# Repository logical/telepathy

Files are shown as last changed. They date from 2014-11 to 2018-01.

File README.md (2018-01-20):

THIS PROJECT IS DISCONTINUED FOR NOW.

The research is proving more difficult than I have hoped and there are alternatives available.

This is telepathy the mostly HARDWARE project not telepathy the software project
Sorry for my lack of creativity in choosing a name.

This poject contains an EXPERIMENTAL wireless eeg circuit.

GOAL
------
This project is under development so it is not working. I welcome suggestions.

The goal is to do brain computer interface experments.I want to make a wireless headband that runs
on a battery. 

It contains.

STATUS
------
I made one pcb but it didn't work. I'm still interested in the project so I am currently doing 
a complete redesign of the hardware. I will be etching the boards myself they will be single sided SMT 
and divided in sections.Here are some of the changes I'm planning. 

1. Split the device into sections for power, amplifier and input/output.
2. Replace the wireless module and pic with a wireless capable microcontroller. (telepathy with esp8266?)
3. The whole design will be based on active electrodes.

ELECTRODES: 

I have 2 designs for active electrodes. Active dry electrodes and active noncontact electrodes.
The dry electrodes are based on the openeeg design. The noncontact electrodes are based on a design I found here:

http://www.isn.ucsd.edu/pubs/bsn10.pdf

I'm assuming it is creative commons.

AMPLIFIER BOARD:

The amplifier board is under testing I plan to use one filter for aliasing and filter the rest in software. None
 of the resistor and capacitor values are decided yet.  
I have the source voltage at 3.3v from a cell phone battery. So far I can pick up a heartbeat .

EEGDATA:

A GUI software program for linux that retreives the data from the /dev/rfcomm0 bluetooth serial terminal
and analyzes and displays the data. I started the project in C but it was more convenient to write the data analysis portion in C++. 

On my system I use these commands to setup the bluetooth serial port.

 	#find the address
 	$hcitool scan
	#bind the address
	$sudo rfcomm bind rfcomm0 device_address
	
For BLE

	#find the adapter address
	$hcitool dev
	#find the device address
	$sudo hcitool -i hci0 lescan

Then you need to run any programs that access serial terminal as root unless you have sufficient permission.

FIRMWARE:

The firmware is for a PIC microcontroller 16f1788 and a bluetooth serial module hc-05.

I have wrote a bootloader so I can more easily install firmware.The bootloader sets the hc-05 up at 38400 and waits for a program.
When the program successfully loads it sets a byte in ee memory.when the FLASH command is sent to the program it erases the byte
so the bootloader will again wait for a progam. You can use a standard serial terminal to send the program but you have to set a long delay (~30ms) between characters so the program has time to write. Custom coding the serial interface for the bootloader would be faster but this works for now.

Hopefully I have no glitches in the bootloader or a firmware update could brick the device! 
If so the glitch would have to be fixed and the bootloader reprogrammed.

The microcontroller first sets up the hc-05 at 230400, then wait for a request.When it receives  a request it begins sampling the analog to digital converter and sending the samples to the hc-05.

I have included the makefiles so they should build with the make command but they may require modification . MPLABX should be able to load them as a makefile project but I have not tried.

SCHEMATIC:

I'm developing the amplifier board first. amplifier-board.png is the current design.

DISCLAIMER:

This project is an EXPERIMENT. I make no claims that it actually does anything.It may be harmful to 
individuals or property.
THIS DEVICE AND SOFTWARE MAY BE DANGEROUS. DO NOT BUILD IT.

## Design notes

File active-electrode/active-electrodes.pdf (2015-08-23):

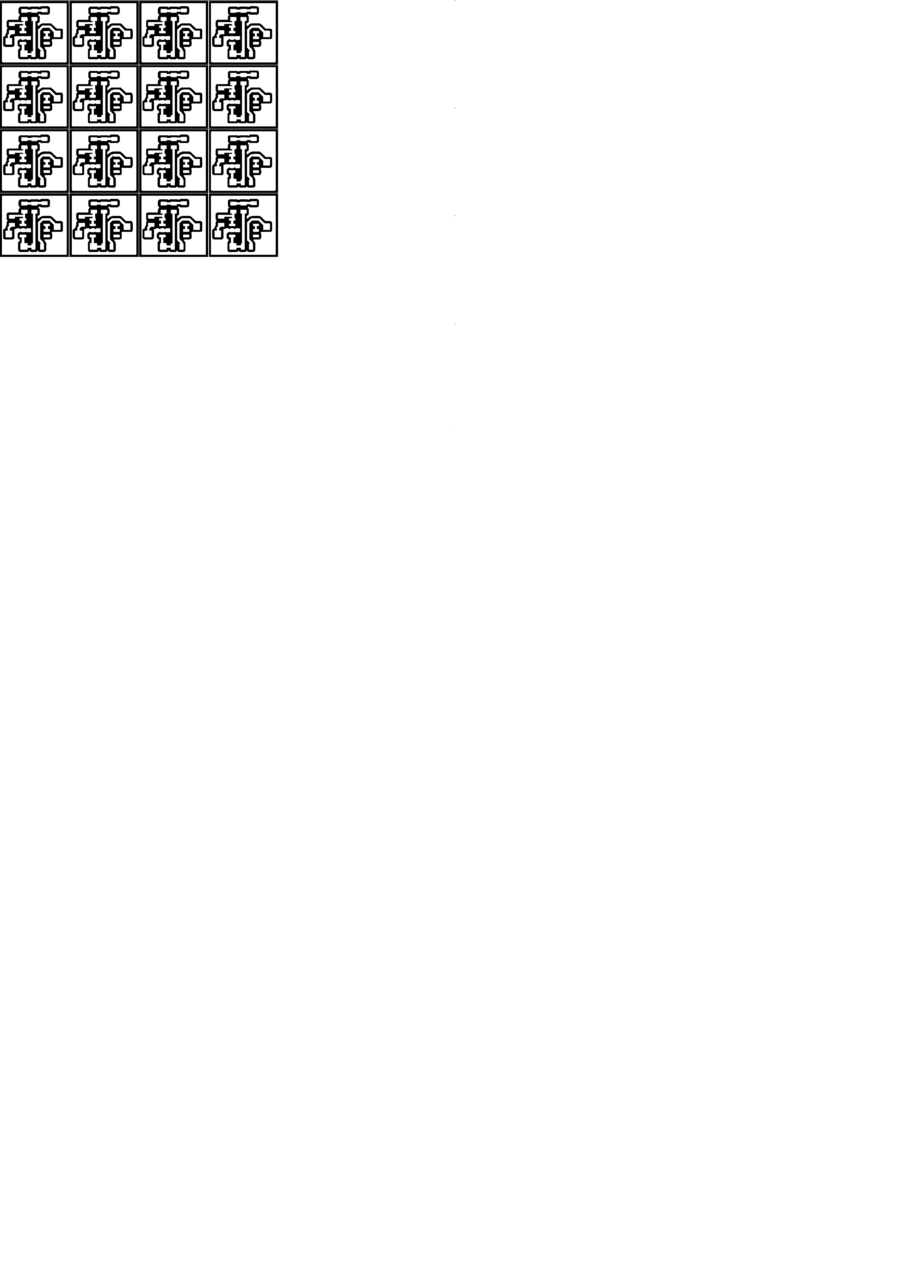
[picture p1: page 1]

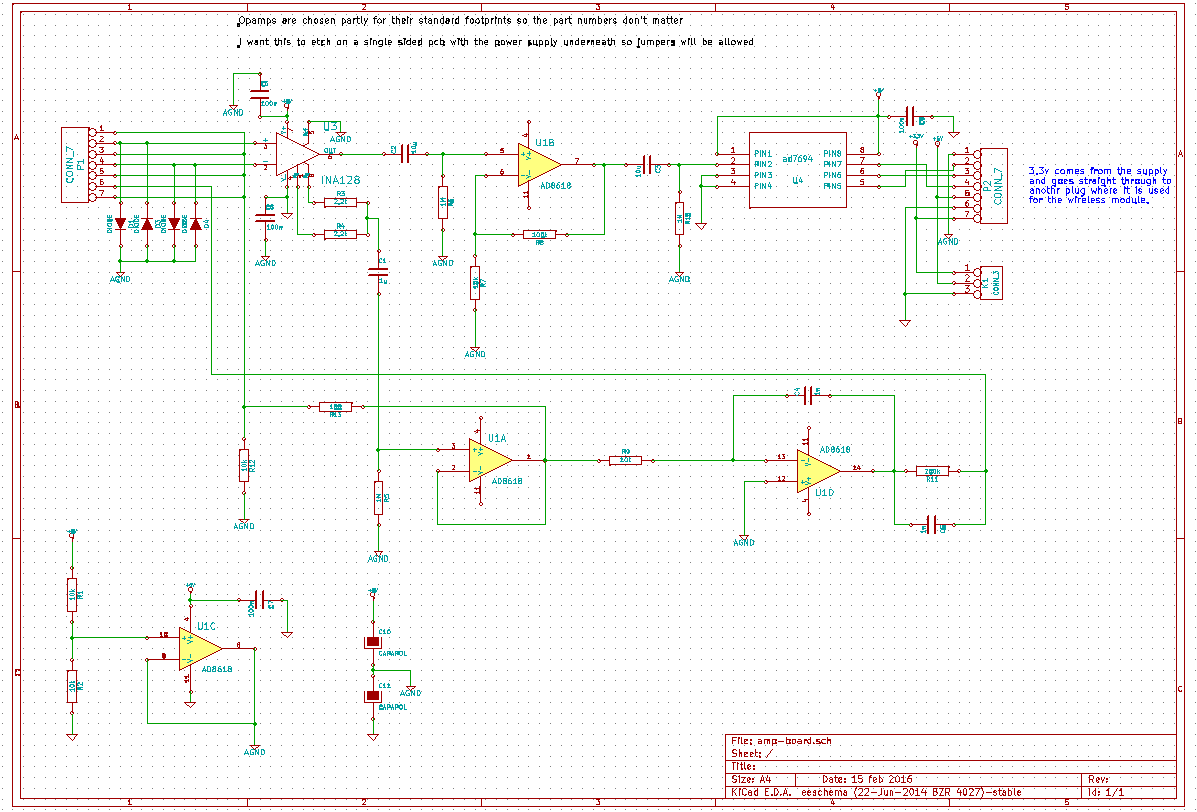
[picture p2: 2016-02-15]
amplifier-board.png

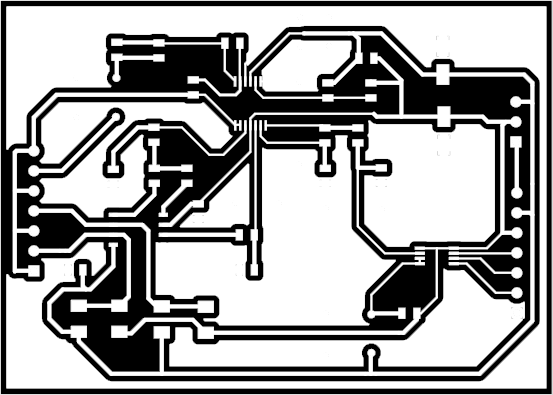
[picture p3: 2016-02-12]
amplifier-board/amp-board-F_Cu.png

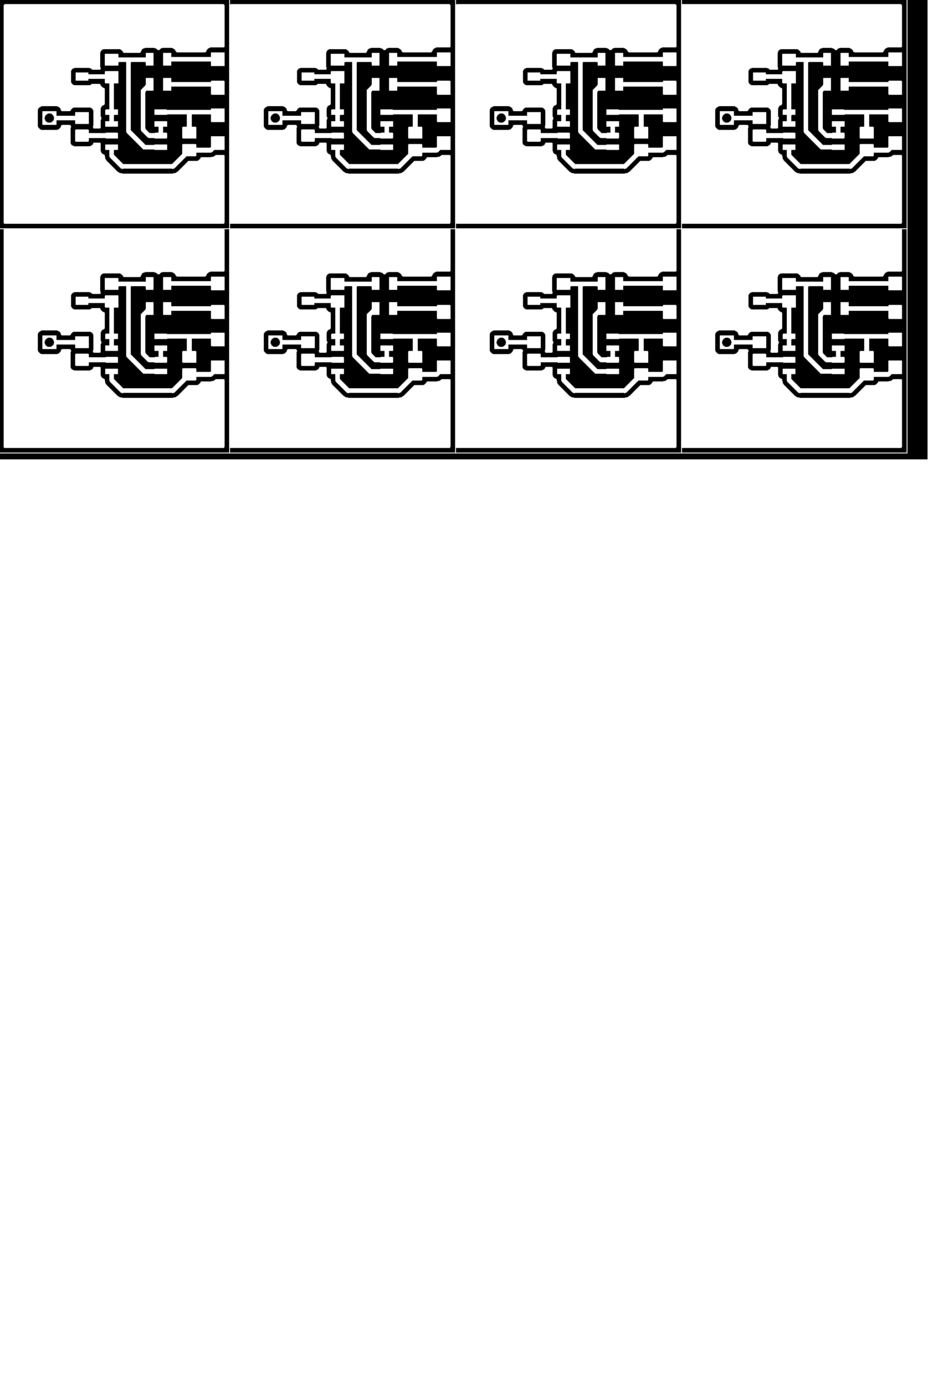
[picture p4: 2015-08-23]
noncontact-electrodes/noncontact-electrodes-F_Cu.png

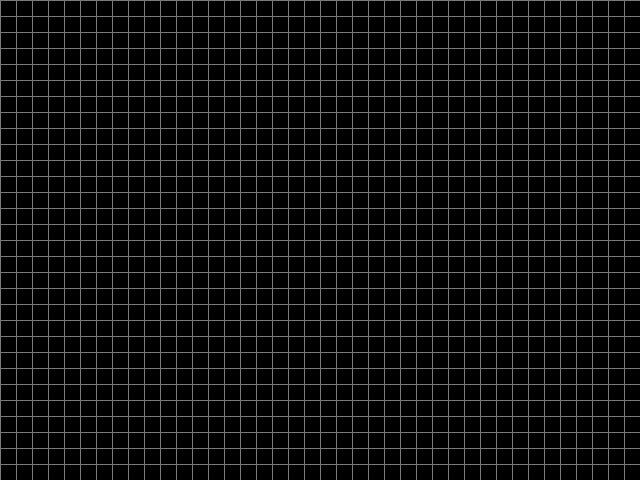
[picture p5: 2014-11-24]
eegdata/grid.png

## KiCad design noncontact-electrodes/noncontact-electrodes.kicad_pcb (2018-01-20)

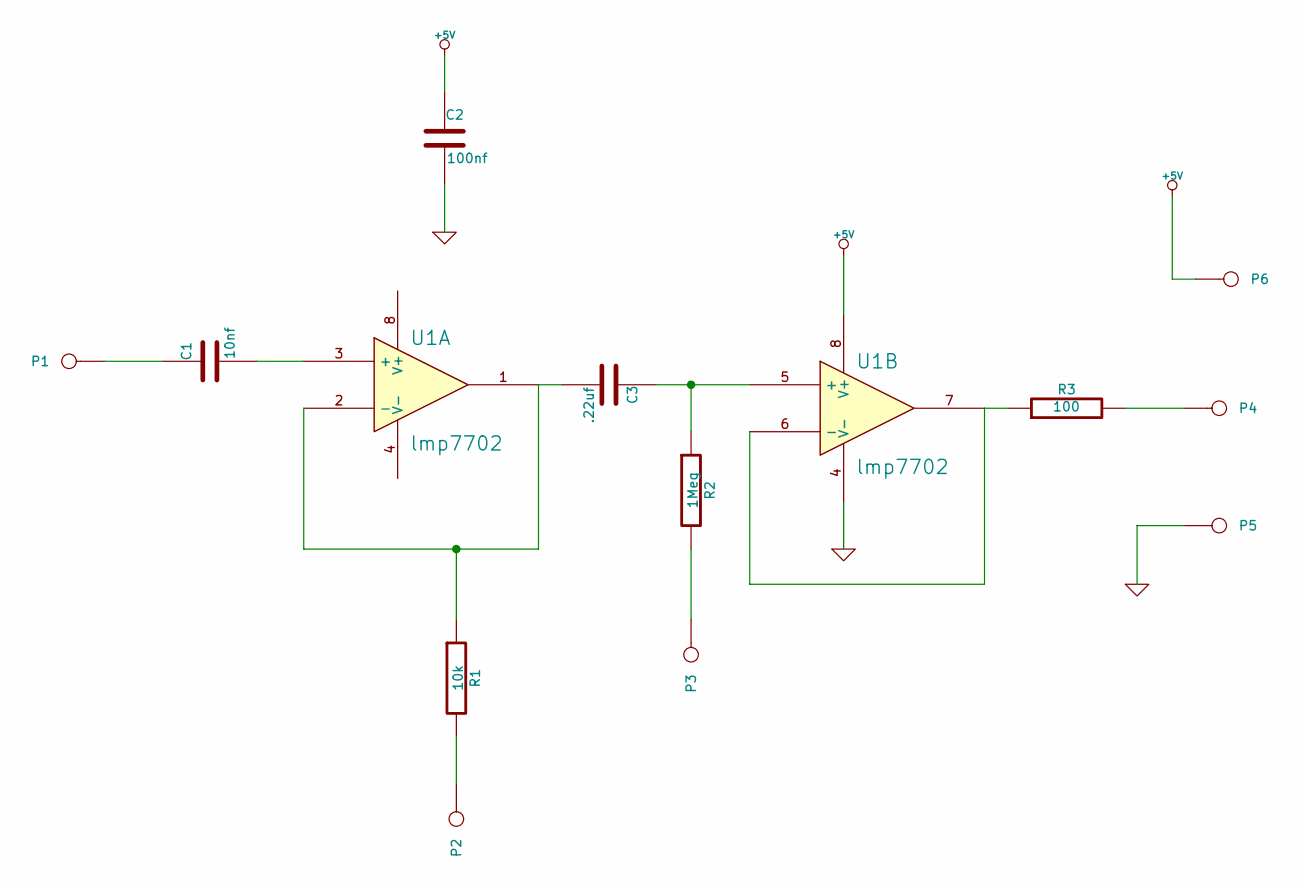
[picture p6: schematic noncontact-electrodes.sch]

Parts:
C1: 10nf
C2: 100nf
C3: .22uf
P1, P2, P3, P4, P5, P6: CONN_1
R1: 10k
R2: 1Meg
R3: 100
U1: lmp7702

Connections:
+5V: C2.1, P6.1, U1.8 (V+)
GND: C2.2, P5.1, U1.4 (V-)
unnamed: P2.1, R1.2
unnamed: C1.1, P1.1
unnamed: P4.1, R3.2
unnamed: P3.1, R2.2
unnamed: C1.2, U1.3 (+)
unnamed: C3.2, R1.1, U1.1, U1.2 (-)
unnamed: R3.1, U1.6 (-), U1.7
unnamed: C3.1, R2.1, U1.5 (+)

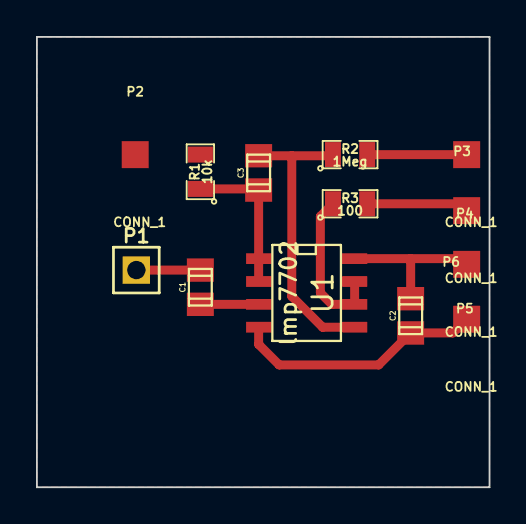
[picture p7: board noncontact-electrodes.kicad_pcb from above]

Board: 2 copper layers, 25.1 x 25.0 mm, 13 parts (0 on the bottom side), 10 nets.

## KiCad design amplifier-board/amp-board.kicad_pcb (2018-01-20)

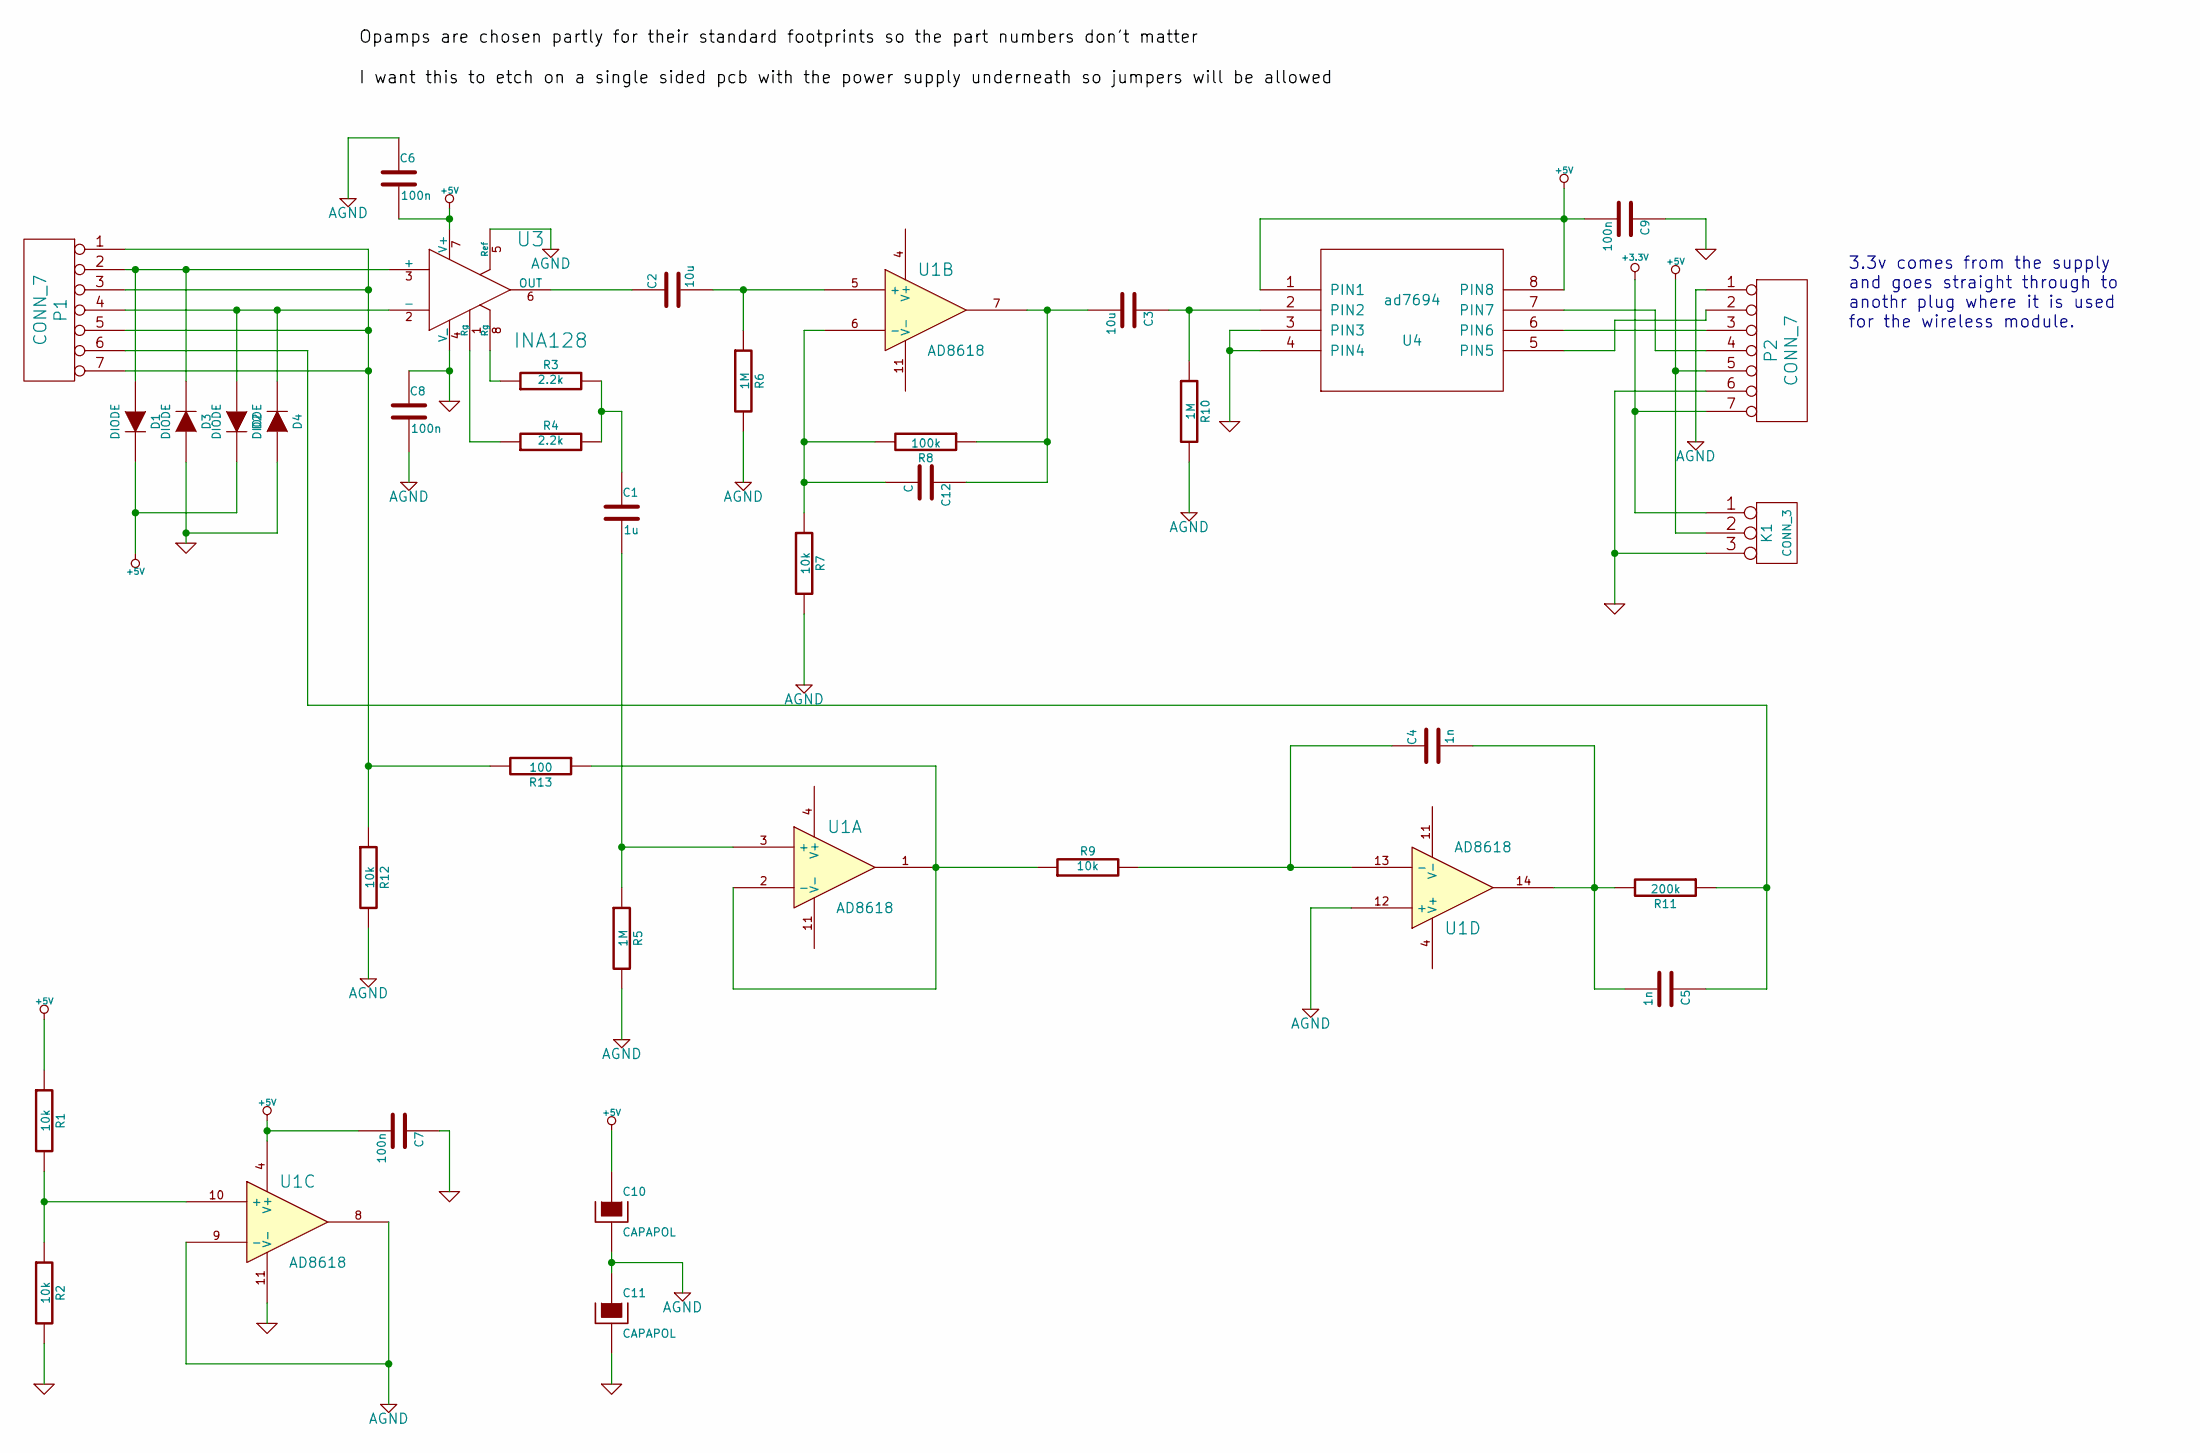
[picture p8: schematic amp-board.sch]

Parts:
C1: 1u
C2, C3: 10u
C4, C5: 1n
C6, C7, C8, C9: 100n
C10, C11: CAPAPOL
C12: C
D1, D2, D3, D4: DIODE
K1: CONN_3
P1, P2: CONN_7
R1, R2, R7, R9, R12: 10k
R3, R4: 2.2k
R5, R6, R10: 1M
R8: 100k
R11: 200k
R13: 100
U1: AD8618
U3: INA128
U4: ad7694; MODULE

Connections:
+3.3V: K1.1, P2.7
+5V: C6.2, C7.2, C9.2, C10.1, D1.2 (K), D2.2 (K), K1.2 (PM), P2.5, R1.1, U1.4 (V+), U3.7 (V+), U4.1 (PIN1), U4.8 (PIN8)
AGND: C6.1, C8.2, C10.2, C11.1, P2.1, R5.2, R6.2, R7.2, R10.2, R12.2, U1.8, U1.9 (-), U1.12 (+), U3.5 (Ref)
GND: C7.1, C8.1, C9.1, C11.2, D3.1 (A), D4.1 (A), K1.3, P2.6, R2.2, U1.11 (V-), U3.4 (V_), U4.3 (PIN3), U4.4 (PIN4)
unnamed: R9.1, R13.1, U1.1, U1.2 (-)
unnamed: C4.1, R9.2, U1.13 (-)
unnamed: C4.2, C5.2, R11.2, U1.14
unnamed: C5.1, P1.6, R11.1
unnamed: C1.2, R5.1, U1.3 (+)
unnamed: C1.1, R3.2, R4.2
unnamed: C3.1, R10.1, U4.2 (PIN2)
unnamed: C3.2, C12.1, R8.1, U1.7
unnamed: R1.2, R2.1, U1.10 (+)
unnamed: C2.2, R6.1, U1.5 (+)
unnamed: C2.1, U3.6 (OUT)
unnamed: R4.1, U3.1 (Rg)
unnamed: R3.1, U3.8 (Rg)
unnamed: D2.1 (A), D4.2 (K), P1.4, U3.2 (-)
unnamed: C12.2, R7.1, R8.2, U1.6 (-)
unnamed: D1.1 (A), D3.2 (K), P1.2, U3.3 (+)
unnamed: P2.3, U4.6 (PIN6)
unnamed: P2.2, U4.5 (PIN5)
unnamed: P2.4, U4.7 (PIN7)
unnamed: P1.1, P1.3, P1.5, P1.7, R12.1, R13.2

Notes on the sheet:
3.3v comes from the supply and goes straight through to anothr plug where it is used for the wireless module.

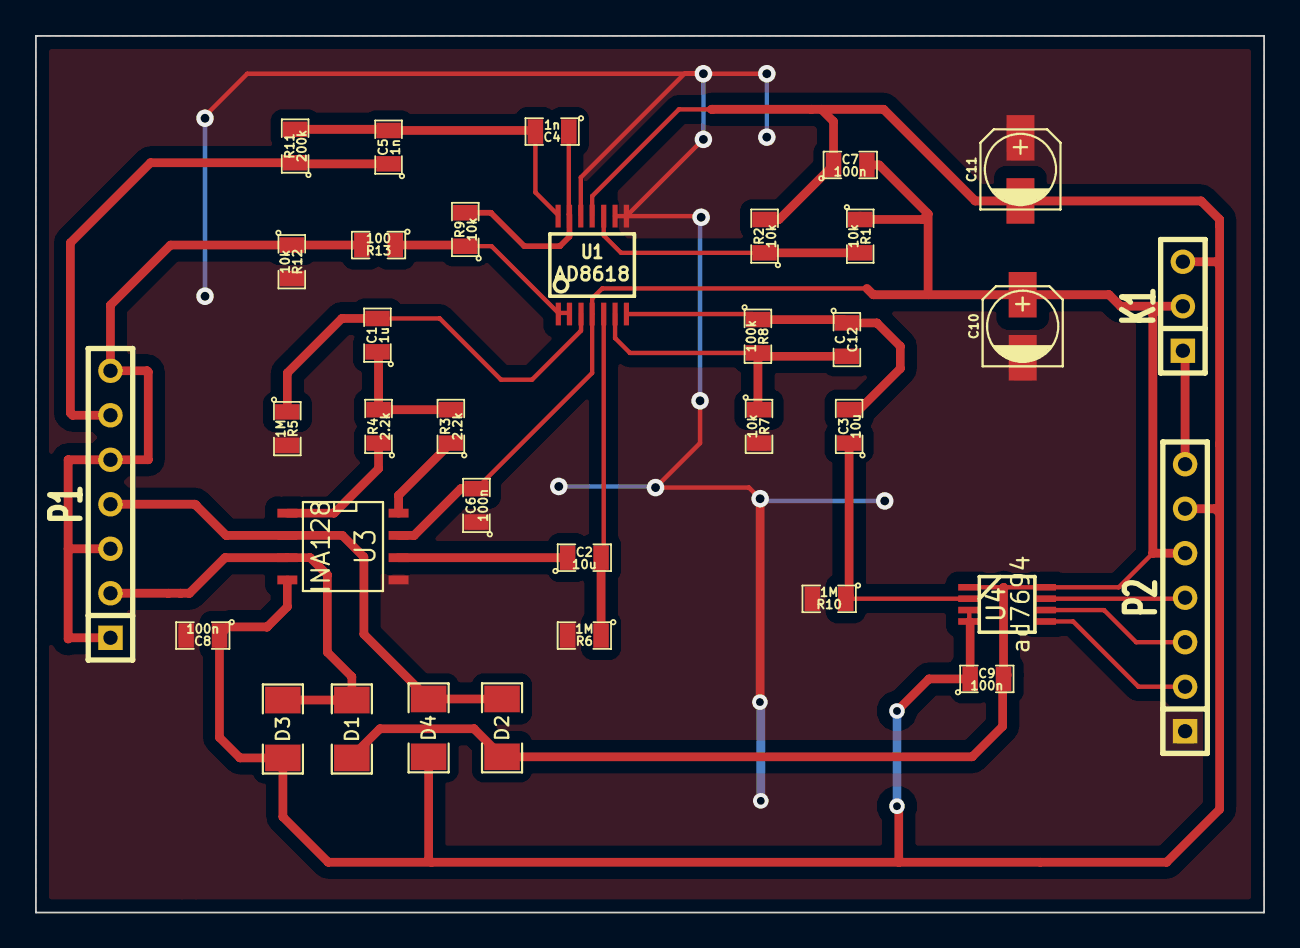
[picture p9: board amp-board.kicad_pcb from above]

Board: 2 copper layers, 70.1 x 50.0 mm, 35 parts (0 on the bottom side), 24 nets.

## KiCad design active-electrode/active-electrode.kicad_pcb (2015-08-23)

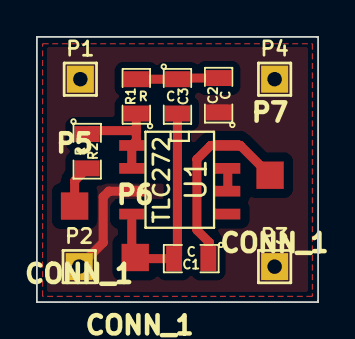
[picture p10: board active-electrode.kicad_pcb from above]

Board: 2 copper layers, 15.6 x 14.7 mm, 13 parts (0 on the bottom side), 7 nets.

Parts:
C1, C2, C3: C; SM0805
P1, P2, P3, P4: CONN_1; SIL-1
P5, P6, P7: CONN_1; 1PIN_SMD
R1, R2: R; SM0805
U1: TLC272; SO8E

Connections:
+5V: C1.1, P7.1, U1.8
GND: C1.2, C3.2, P6.1, U1.4
unnamed: U1.6, U1.7
unnamed: C2.2, C3.1, R1.2
unnamed: R1.1, R2.1, U1.1, U1.2
unnamed: P5.1, R2.2
unnamed: C2.1, P1.1, P2.1, P3.1, P4.1, U1.3

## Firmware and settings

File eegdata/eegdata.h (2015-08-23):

#ifndef EEGDATA_H
#define EEGDATA_H

#include <gtk/gtk.h>
#include <gdk/gdk.h>

#include <glib/gprintf.h>
#include "cvanalyze.h"
#include "eegdatarxtx.h"
 
#ifdef __cplusplus
extern "C" {
#endif

#define FRAMEDELAY 50
#define DEFAULT_FILE    "./telepathy-eeg.dat"
#define RXTXPROCESS     "./eegdatarxtx"
#define FIFONAME	"./eegdatafifo"
#define SAVE_FILE	"./eegdatasettings"
       

  
#define UI_FILE "ui3.ui"
#define SCOPEWIDTH 640
#define SCOPEHEIGHT 480
#define WRITESIZE 32 //number of samples to write at once
#define YSCALE ((float)SCOPEHEIGHT/(float)MAXSAMPLE)
#define XSCALE (SCOPEWIDTH/(SAMPLESIZE/2))
#define RESISTOR 255 //this sets the resistor value that sets the final amplifier gain  

#define DEFAULT_COM	"/dev/rfcomm1"
#define DEFAULT_BAUD	B230400 

  
pthread_t rxthread;

char mode;

GtkWidget *video,*signalview,*chan1check,*chan2check,*chan3check,*chan4check,*timecheck,*freqcheck,*savedialog,*startbutton,*devicechoice,*rangespin;
GtkWidget *savename[TRIGGERS],*saveaction[TRIGGERS],*savebutton[TRIGGERS],*deletebutton[TRIGGERS],*activebutton[TRIGGERS];
GdkPixbuf *grid;




double volts,trig,chron;
unsigned short selectedrow;
unsigned char RequestedRange;

cairo_surface_t *background,*scope;

union{
    struct{
    unsigned DONE   :1;  
    unsigned DATA   :1;  
    };

}controlbits;



GtkWidget* create_window (void);
void drawingarea1_draw_event_cb(GtkWidget *widget, gpointer gdata);
void drawingarea2_draw_event_cb(GtkWidget *widget, gpointer gdata);
void open_save_patterns( GtkWidget *widget , gpointer data);
void save_pattern( GtkWidget *widget , gpointer data);
void start( GtkWidget *widget , gpointer data);
void destroy (GtkWidget *widget, gpointer data);

void microsleep(unsigned int us);
void trace(cairo_t* sc,unsigned short *data,unsigned int size);
int SetupConnection(int port, int baudRate);
int receive(int port,unsigned char *rxbuffer,unsigned int length);
void fakepackets(unsigned int length);
void read_settings_file(void);
void save_settings_file(void);
void getdata(void);
int setrange(int range);
void writepackets(void);


#ifdef __cplusplus
} 
#endif


#endif

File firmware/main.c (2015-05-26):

/*
 * File:   main.c
 * Author: logical
 *
 * Created on December 7, 2014, 10:37 AM
 *   The byte format is:
 *
 * MSB channel 1/LSB channel 1/MSB channel 2/LSB channel 2/MSB channel 3/LSB channel 3/MSB channel 4/LSB channel 4/
 * the control character are:
 *
 * s : sample 256 samples and send 512 bytes per channel
 *
 * t :to transmitter by sending "hello\n"
 *
 * r XXX :set gain of amplifier by increasing and decreasing rf of non inverting opamp. 
 *
 *
 */

#include <string.h>
#include <stdlib.h>
#include <pic16f1788.h>
#include <xc.h>

#define NO_BIT_DEFINES
#define BOOTLOAD
#ifndef BOOTLOAD
#pragma config FOSC = INTOSC    // Oscillator Selection (INTOSC oscillator: I/O function on CLKIN pin)
#pragma config WDTE = OFF       // Watchdog Timer Enable (WDT disabled)
#pragma config PWRTE = OFF      // Power-up Timer Enable (PWRT disabled)
#pragma config MCLRE = ON       // MCLR Pin Function Select (MCLR/VPP pin function is MCLR)
#pragma config CP = OFF         // Flash Program Memory Code Protection (Program memory code protection is disabled)
#pragma config CPD = OFF        // Data Memory Code Protection (Data memory code protection is disabled)
#pragma config BOREN = OFF      // Brown-out Reset Enable (Brown-out Reset disabled)
#pragma config CLKOUTEN = OFF   // Clock Out Enable (CLKOUT function is disabled. I/O or oscillator function on the CLKOUT pin)
#pragma config IESO = ON      // Internal/External Switchover (Internal/External Switchover mode is disabled)
#pragma config FCMEN = OFF      // Fail-Safe Clock Monitor Enable (Fail-Safe Clock Monitor is disabled)

#pragma config WRT = OFF        // Flash Memory Self-Write Protection (Write protection off)
#pragma config VCAPEN = OFF     // Voltage Regulator Capacitor Enable bit (Vcap functionality is disabled on RA6.)
#pragma config PLLEN = OFF      // PLL Enable (4x PLL disabled)
#pragma config STVREN = OFF     // Stack Overflow/Underflow Reset Enable (Stack Overflow or Underflow will not cause a Reset)
#pragma config BORV = HI        // Brown-out Reset Voltage Selection (Brown-out Reset Voltage (Vbor), low trip point selected.)
#pragma config LPBOR = OFF      // Low Power Brown-Out Reset Enable Bit (Low power brown-out is disabled)
#pragma config LVP = OFF        // Low-Voltage Programming Enable (High-voltage on MCLR/VPP must be used for programming)

#endif


/*pin defines*/

#define ERROR_PIN PORTAbits.RA6

/*
 * MC4130 digital potentiometer 
 * 
 */

#define POT_CS_PIN PORTCbits.RC1
#define ADC_CONV_PIN PORTCbits.RC2
#define SCK_PIN PORTCbits.RC3
#define SDI_PIN PORTCbits.RC4
#define SDO_PIN PORTCbits.RC5

/*
 * AD409 analog multiplexer
 */

#define MPX_A_PIN PORTBbits.RB0
#define MPX_B_PIN PORTBbits.RB1

/*
 * These outputs ground unused multiplexer inputs to prevent crosstalk
 */

#define GND_IN_0 PORTBbits.RB2
#define GND_IN_1 PORTBbits.RB3
#define GND_IN_2 PORTBbits.RB4
#define GND_IN_3 PORTBbits.RB5


/*
 * UART for the HC-05
 */
#define CMD_PIN PORTCbits.RC0
#define TX_PIN	PORTCbits.RC6
#define RX_PIN	PORTCbits.RC7



#define BAUD_230400 2
#define BAUD_38400 1

#define PACKETSIZE 8
#define MAXSAMPLE 65535 

struct{
    unsigned char size;
    unsigned char elems[64];
    unsigned flag :1;
}rxbuffer,txbuffer;


#define XON 0x11
#define XOFF 0x13
#define START 0x12
#define STOP 0x14
#define TESTMODE 0x07

union{
    struct{
    unsigned FLOW    :1;
    unsigned DATA    :1; 
    unsigned TEST    :1;
    unsigned RX      :1;
    unsigned TX      :1;
    unsigned CH1     :1;
    unsigned CH2     :1;
    };

}controlbits;


unsigned char delay_count1;


void delay_100us(unsigned int count){
/*
 *  ; Delay = 0.0001 seconds
 *  ; Clock frequency = 8 MHz
 *  ;798 cycles
 * 
 */
    while(count--){
        asm("movlw	0x41");
        asm("movwf	_delay_count1");
        asm("Delay_1    ");
        asm("decfsz	_delay_count1, f");
        asm("goto	Delay_1");
    }

}

void flasherror(unsigned char flashes){
    for(unsigned char f=0;f<flashes;f++){
            ERROR_PIN=1;
            delay_100us(2000);
            ERROR_PIN=0;
            delay_100us(2000);
        }
            delay_100us(5000);
}
unsigned int bytecount=0;

void interrupt isr(){

    if(PIR1bits.RCIF==1) {
        unsigned char rx=RCREG;
        if(rx==START)
            controlbits.DATA = 1;
        else if(rx==XON)
            controlbits.FLOW = 1;
        else if(rx==STOP){
            controlbits.DATA = 0;
            controlbits.TEST = 0;
        }
        else if(rx==TESTMODE)
            controlbits.TEST=1;
        else {
            rxbuffer.elems[rxbuffer.size] = rx;

            if(rxbuffer.elems[rxbuffer.size]==10){//linefeed
                rxbuffer.elems[rxbuffer.size+1]='\0';
                rxbuffer.flag=1;
            }
            rxbuffer.size++;
        }
        PIR1bits.RCIF=0;
    }
}
/*
 * this resistor is the grounded resistor of a non inverting opamp
 * The ADC and digital potentiometer are on the SPI bus 
 * 
 */

void setresistor(unsigned char value){
    ADC_CONV_PIN=1;
    POT_CS_PIN=0;
    SSPBUF = 0;
    while(!SSPSTATbits.BF);
    SSPBUF = value;
    while(!SSPSTATbits.BF);
    POT_CS_PIN=1;
    ADC_CONV_PIN=0;
    delay_100us(1);
}



#define INTERVAL 120
void feedtransmitter(){
/*
 *    the loop counter will count the wait time to give an more accurate delay
 */  
    
    unsigned int counter=0;
    while(txbuffer.size>0){ 
        TXREG = txbuffer.elems[--txbuffer.size];
        while(!TXSTAbits.TRMT)counter++;
    }
    while(counter<INTERVAL)counter++;
}

/*
 * 256 sa/s is a good sample rate for eeg
 */
void senddata(void){
    unsigned int count=0;
    txbuffer.size=0;
    while(controlbits.DATA){
            txbuffer.elems[txbuffer.size++]=XOFF;
            count=0;
            PORTB=0b00111000;
            MPX_A_PIN=0;                    //set multiplexer channel
            MPX_B_PIN=0;
            delay_100us(1);                 //settling time
            ADC_CONV_PIN=1;                 //start conversion
            delay_100us(1);
            ADC_CONV_PIN=0;
            PIR1bits.SSP1IF=0;
             SSPBUF = 0x00;                 // Write dummy data byte to the buffer to initiate transmission
            while(!SSPSTATbits.BF)count++;  //receive MSB first
            txbuffer.elems[txbuffer.size++] =SSPBUF;
            PIR1bits.SSP1IF=0;          
            SSPBUF = 0x00;              
            while(!SSPSTATbits.BF)count++;
            txbuffer.elems[txbuffer.size++]=SSPBUF;
            while(count<INTERVAL)count++;


            count=0;
            PORTB=0b00110101;
            MPX_A_PIN=1;
            MPX_B_PIN=0;
            delay_100us(1);
            ADC_CONV_PIN=1;
            delay_100us(1);
            ADC_CONV_PIN=0;
            PIR1bits.SSP1IF=0;
            SSPBUF = 0x00;
            while(!SSPSTATbits.BF)count++;
            txbuffer.elems[txbuffer.size++]=SSPBUF;
            PIR1bits.SSP1IF=0;
            SSPBUF = 0x00;
            while(!SSPSTATbits.BF)count++;
            txbuffer.elems[txbuffer.size++]=SSPBUF;
            while(count<INTERVAL)count++;

            count=0;
            PORTB=0b00101110;
            MPX_A_PIN=0;
            MPX_B_PIN=1;
            delay_100us(1);//settling time
            ADC_CONV_PIN=1;
            delay_100us(1);
            ADC_CONV_PIN=0;
            PIR1bits.SSP1IF=0; 
            SSPBUF = 0x00;     
            while(!SSPSTATbits.BF)count++;

            txbuffer.elems[txbuffer.size++]=SSPBUF;
            PIR1bits.SSP1IF=0;         
            SSPBUF = 0x00;              
            while(!SSPSTATbits.BF)count++;
            txbuffer.elems[txbuffer.size++]=SSPBUF;
            while(count<INTERVAL)count++;

            count=0;
            PORTB=0b00011111;
            MPX_A_PIN=1;
            MPX_B_PIN=1;
            delay_100us(1);
            ADC_CONV_PIN=1;
            delay_100us(1);
            ADC_CONV_PIN=0;
            PIR1bits.SSP1IF=0;         
            SSPBUF = 0x00;             
            while(!SSPSTATbits.BF)count++;
            txbuffer.elems[txbuffer.size++]=SSPBUF;
            PIR1bits.SSP1IF=0;
            SSPBUF = 0x00;
            while(!SSPSTATbits.BF)count++;
            txbuffer.elems[txbuffer.size++]=SSPBUF;
            while(count<INTERVAL)count++;

            txbuffer.elems[txbuffer.size++]=XON;

            feedtransmitter();

    }
}

/*
 *  testmode sends 4 sawtooth waves
 */
void test(void){
    int speed=2;
    union {
        unsigned char ch[2];
        unsigned short n;
    } channel[4];

    while(controlbits.TEST){
        txbuffer.elems[txbuffer.size++]=XOFF;
        txbuffer.elems[txbuffer.size++]=channel[0].ch[0];
        txbuffer.elems[txbuffer.size++]=channel[0].ch[1];;
        txbuffer.elems[txbuffer.size++]=channel[1].ch[0];
        txbuffer.elems[txbuffer.size++]=channel[1].ch[1];;
        txbuffer.elems[txbuffer.size++]=channel[2].ch[0];
        txbuffer.elems[txbuffer.size++]=channel[2].ch[1];;
        txbuffer.elems[txbuffer.size++]=channel[3].ch[0];
        txbuffer.elems[txbuffer.size++]=channel[3].ch[1];;
        txbuffer.elems[txbuffer.size++]=XON;

        channel[0].n+=speed;
        channel[1].n+=speed*2;
        channel[2].n+=speed*3;
        channel[3].n+=speed*4;
        if(channel[0].n >= MAXSAMPLE)channel[0].n=0;
        if(channel[1].n >= MAXSAMPLE)channel[1].n=0;
        if(channel[2].n >= MAXSAMPLE)channel[2].n=0;
        if(channel[3].n >= MAXSAMPLE)channel[3].n=0;
        delay_100us(60);

        feedtransmitter();
    }
}



void SetupADC(void){
/*
 * The adc is a 16 bit spi ltc1864
 */
    SSPCON1bits.SSPM=0b0000; 
    SSPCON1bits.SSPEN=1;



}

void SetupUART(unsigned char speed){
/*
 *  38400bps = 8e6/(4*(51+1)) = 38461
 *  230400bps = 8e6/(4*(8+1)) = 222222
 */



    RCSTAbits.SPEN=0;
    if(speed==BAUD_230400){
        SPBRG=8;
        BAUDCTLbits.BRG16=1;
	TXSTAbits.BRGH=1;
    }
    else if(speed==BAUD_38400){
	SPBRG=51;
        BAUDCTLbits.BRG16=1;
	TXSTAbits.BRGH=1;
    }
    TXSTAbits.SYNC=0;
    RCSTAbits.SPEN=1;
    RCSTAbits.CREN=1;
    RCSTAbits.RX9=0; 

    PIE1bits.RCIE=1;
    INTCONbits.PEIE=1;

}




void TXstring(const char *stringtosend){
    unsigned char i=0;
    controlbits.FLOW=1;
    while(i<strlen(stringtosend)){
        if(controlbits.FLOW ){
            TXREG = stringtosend[i++];
            while(!TXSTAbits.TRMT);
        }
    }
}



void setHM10uart(void){
    SetupUART(BAUD_38400); 
    delay_100us(10);
    TXstring("AT+UART?\r\n");
    unsigned char response[32];
    ERROR_PIN=1;

    while(!rxbuffer.flag);
    rxbuffer.flag=0;
    ERROR_PIN=0;

    strcpy(response,rxbuffer.elems);
    rxbuffer.size=0;
    rxbuffer.flag=0;

    if(strcmp(response,"+UART:230400,1,0\r\nOK\r\n")!=0){
        TXstring("AT+UART=230400,1,0\r\n");

        ERROR_PIN=1;

        while(!rxbuffer.flag);

        ERROR_PIN=0;

        strcpy(response,rxbuffer.elems);
        if(strcmp(response,"OK\r\n")!=0)while(1)flasherror(5);
        rxbuffer.size=0;
        rxbuffer.flag=0;

    }
}

void resetHC05(){

    TXstring("AT+RESET\r\n");
    unsigned char response[32];

    ERROR_PIN=1;

    while(!rxbuffer.flag);

    ERROR_PIN=0;

    strcpy(response,rxbuffer.elems);
    if(strcmp(response,"OK\r\n")!=0)while(1)flasherror(2);
    rxbuffer.size=0;
    rxbuffer.flag=0;
}

void EEwrite(unsigned char addr,unsigned char c){
	EEADRL = addr;
    CFGS=0;
    EEPGD=0;
	EEDATL = c;
    GIE = 0;
    WREN = 1;
    EECON2 = 0x55;
    EECON2 = 0xAA;
    WR = 1;
    WREN = 0;
    GIE = 1;	
    WREN=0;
    while(WR);
	}

void processcommand(void){
    char *token;
    token=strtok(rxbuffer.elems," ");
    if(strcmp(rxbuffer.elems,"FLASH\n")==0){
        TXstring("ERASING PROGRAM\n");
        EEwrite(0, 0);
        asm("RESET");
    }
    else if(strcmp((const char *)token[0],"r")==0){
            token=strtok(NULL," ");
            if(token!=NULL){
                int value=strtol(token,NULL,10);
                setresistor(value);
            }
    }
    rxbuffer.size=0;
    rxbuffer.flag=0;

}

void main(void){

/*
 * set to 8mhz
 */
    OSCCONbits.SCS=00;
    OSCCONbits.IRCF=0b1110;

/*
 * set all pins to digital outputs
 * Open drain for the output to the hc-05 
 * 
 * 
 */
    ANSELA = 0b00000000;
    ANSELB = 0b00000000;
    ANSELC = 0b00000000;
    TRISA = 0b00000000; 
    TRISB = 0b00000000; 
    TRISC = 0b10010000; 
    PORTA=0b00000000;
    PORTB=0b00000000;
    PORTC=0b00000001;
    ODCONCbits.ODCONC0=1;
    ODCONCbits.ODCONC6=1;
    
/* cmd pin is used for hc-05 only
 * hm-10 is in setup mode until it connects
 * pullup resistor  on CMD_PIN will keep module in command mode until ready
 * 
 * 
 */
    CMD_PIN=1;

    SetupADC(); 

    TXSTAbits.SYNC=0;			
    RCSTAbits.SPEN=1;			
    RCSTAbits.CREN=1;
    RCSTAbits.RX9=0;                    
    TXSTAbits.TXEN=1;			
    
    PIE1bits.RCIE=1;
    INTCONbits.PEIE=1;
    INTCONbits.GIE=1;

    rxbuffer.size=0;
    rxbuffer.flag=0;
    
    delay_100us(10000);
    setHM10uart();

    CMD_PIN=0;

    resetHC05();
    delay_100us(10000);


    SetupUART(BAUD_230400);

    delay_100us(100);
    controlbits.CH1=0;
    controlbits.CH2=0;
    while(1){
        if(controlbits.DATA)senddata();
        if(controlbits.TEST)test();
        if(rxbuffer.flag)processcommand();
    }


}

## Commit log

2015-03-14 made program threaded,added circular buffer,added mcp4131 digital pot
2015-03-18 added schematic
2015-03-20 updated draft schematic
2015-03-23 added kicad files
    [$telepathy.brd, telepathy.brd, telepathy.sch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]
2015-03-23 added pcb2gcode script
    [$telepathy.brd, telepathy.brd]
2015-03-24 updated board for cnc mill, added millproject file for pcb2gcode
    [telepathy.brd, telepathy.sch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]
2015-03-26 increase pad and rack widths , added missing connection
    [telepathy.brd, telepathy.sch]
2015-03-27 made board a little smaller
    [telepathy.brd, telepathy.sch]
2015-03-28 changed draft schematic
    [telepathy.brd]
2015-03-29 added a couple capacitors
    [telepathy.brd, telepathy.sch]
2015-03-29 update schematic
    [telepathy.brd, telepathy.sch]
2015-03-31 changed footprints
    [telepathy.brd, telepathy.sch]
2015-03-31 adjusted footprints,added filter components
    [telepathy.brd, telepathy.sch]
2015-04-11 first version
    [telepathy.brd, telepathy.sch]
2015-05-24 added bootloader and makefiles
    [telepathy.brd, telepathy.sch]
2015-08-23 added noncontact electrodes
    [noncontact-electrodes.kicad_pcb, noncontact-electrodes.sch, telepathy.sch]
2015-08-23 added active electrodes
    [$active-electrode.sch, active-electrode.kicad_pcb, active-electrode.sch]
2016-02-12 added amplifier board
    [amp-board.kicad_pcb, amp-board.sch]
2016-02-15 fixed diodes on amplifier pcb
    [$active-electrode.sch, active-electrode.sch, amp-board.kicad_pcb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]
2016-02-15 changed readme and preview schematic
2018-01-20 added discontinued notice
    [amp-board.kicad_pcb, amp-board.sch, noncontact-electrodes.kicad_pcb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]
